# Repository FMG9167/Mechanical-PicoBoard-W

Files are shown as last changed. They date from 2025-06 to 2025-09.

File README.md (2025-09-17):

# Mechanical-PicoBoard-W
A wireless mechanical keyboard made using raspberry pi pico W.
This keyboard has a split spacebar, in which the middle button acts as a function key. The function keys are switched from numbers to QWERASDFZXCV and on the right side, OP[ acts as mouse buttons.




While I was making my Hackpad (Macropad), I saw people making keyboards and I realized that I actually didnt knew how a mechanical keyboard works. So what better way to learn than to make one yourself!

# CAD




# PCB



 


# Firmware

For the Firmware, I used KMK with CircuitPy.

# BOM

1x Raspberyy Pi Pico W   - 599 inr <br>
70x Switches             - 1225 inr <br>
1x Keycap Set            - 2199 inr <br>
5x Stabilizers           - 500 inr <br>
1x Battery Holder        - 59 inr <br>
100x 1N4148 Diodes       - 99 inr <br>
5x PCB                   - 4320 inr <br>
40x Female Berg Strip    - 8.5 inr <br>
40x Male Berg Strip      - 6 inr <br>
M3x16mm Screw            - 0 inr <br>
Case                     - printing legion <br>

### TOTAL 9015.5 INR = 102.67 USD

With shipping it is 109.9 usd

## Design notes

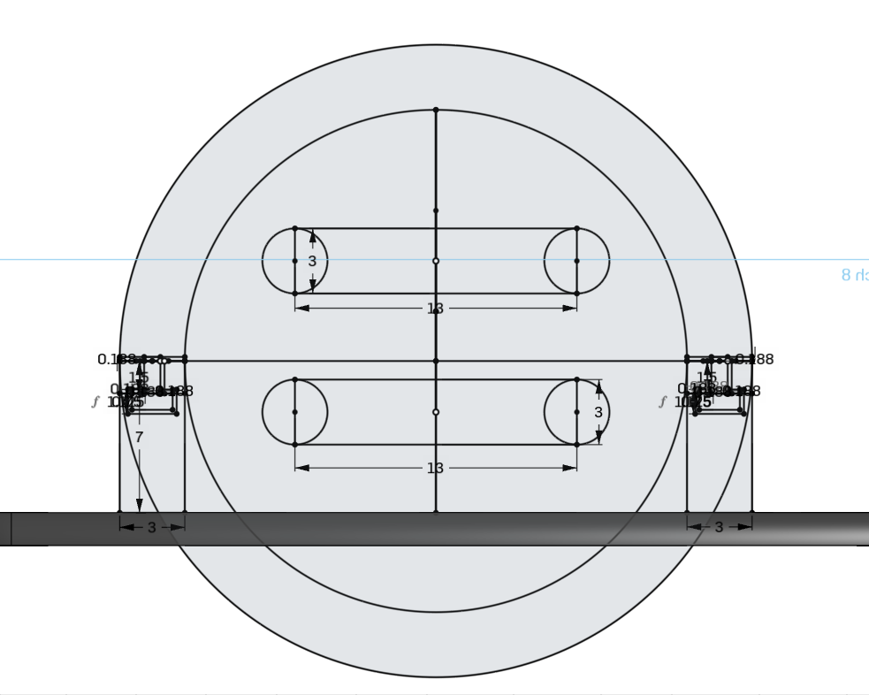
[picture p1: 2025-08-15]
images/Aug-15.png

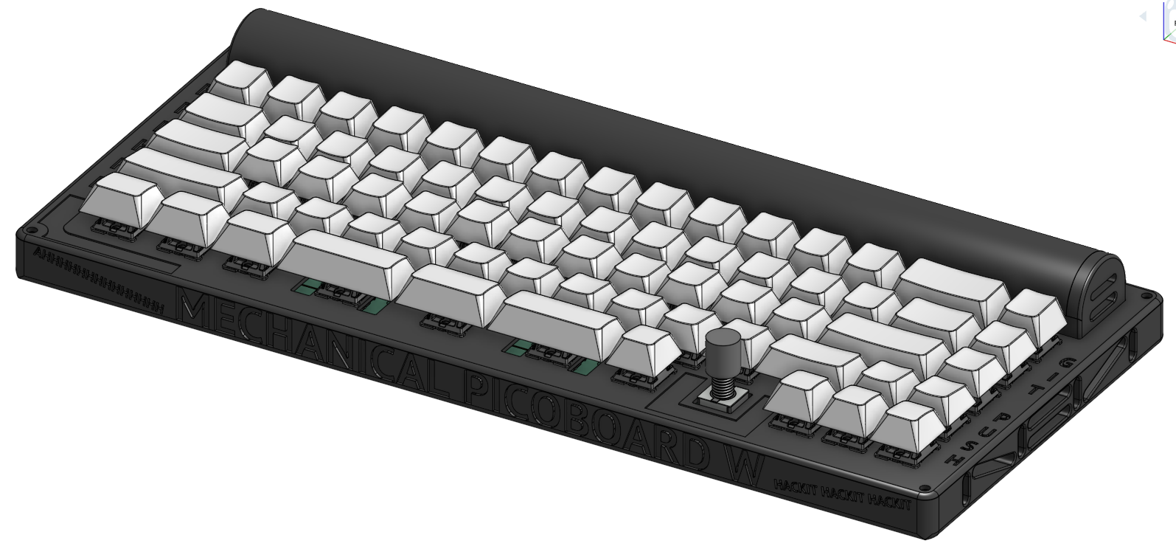
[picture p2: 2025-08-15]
images/Aug-15-4.png

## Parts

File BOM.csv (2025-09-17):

ITEM | UNIT COST | QUANTITY | TOTAL COST | REMARKS | SOURCE
Raspberry Pi Pico W | 599 | 1 | 599 | Other places it is out of stock | https://makerbazar.in/products/raspberry-pi-pico-development-boards?variant=47233117389040
Key Switches | 17.5 | 70 | 1225 | Comes in pack of 10 | https://stackskb.com/store/gateron-g-pro-3-0-yellow-ks-9-linear-switch-pack-of-10/
Key Caps | 2199 | 1 | 2199 |  | https://stackskb.com/store/sikakeyb-doubleshot-pbt-keycaps-two-tone-green-and-grey/
Stabilizers | 80 | 5 | 400 |  | https://stackskb.com/store/durock-white-plate-mount-stabilizers/?attribute_combination=2U
Battery Holder | 59 | 1 | 59 | out of stock literally everywhere | https://roboticsdna.in/product/18650-smd-smt-high-quality-single-battery-holder/
1N4148 Diodes | 0.99 | 100 | 99 | Comes in pack of 100 | https://makerbazar.in/products/dip-rectifier-diode-through-hole?variant=46889718120688
PCB | 864 | 5 | 4320 | Cheapest no customs option | https://robu.in/product/online-pcb-manufacturing-service/
Female berg strip | 0.2125 | 40 | 8.5 | Pack of 40 | https://robocraze.com/products/40x1-female-berg-strip?_pos=1&_sid=3452a2391&_ss=r
Male berg strip | 6.67 | 40 | 6 | Pack of 40 | https://makerbazar.in/products/berg-strip-40-pins
M3x16mm screws | 0 | 4 | 0 | Already have
Case | 0 | 0 | 0 | Printing Legion
 |  | INR | 9015.5
 |  | USD | 102.67 | Excluding shipping
I cant use Aliexpress as it end up costing more than current due to customs T-T
Maker Bazar shipping | 50
Robu shipping | 0
RoboticsDNA shipping | 85
Printing Legion | 500
StacksKB shipping | 100
 |  | INR | 9650.5
 |  | USD | 109.9 | Including taxes and shipping

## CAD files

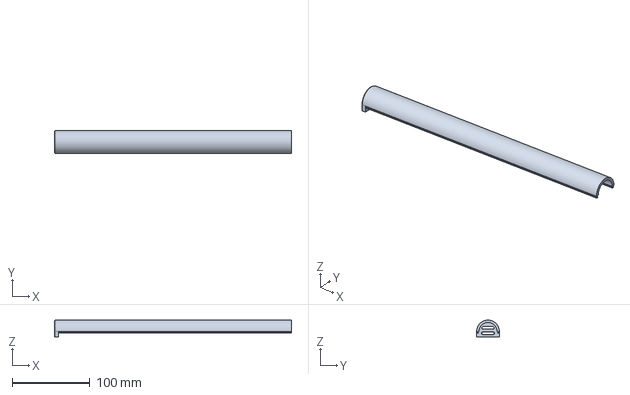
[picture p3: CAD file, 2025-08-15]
CAD/Cover.step
304.5 x 29.2 x 21.5 mm

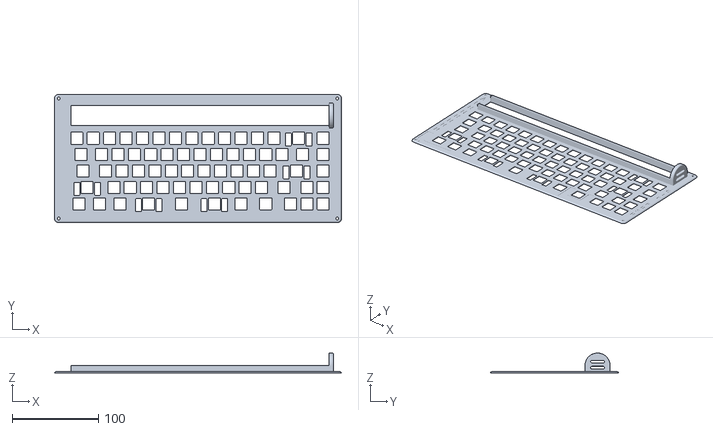
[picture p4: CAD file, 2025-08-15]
Production/Top.stl
332.9 x 148.9 x 23.1

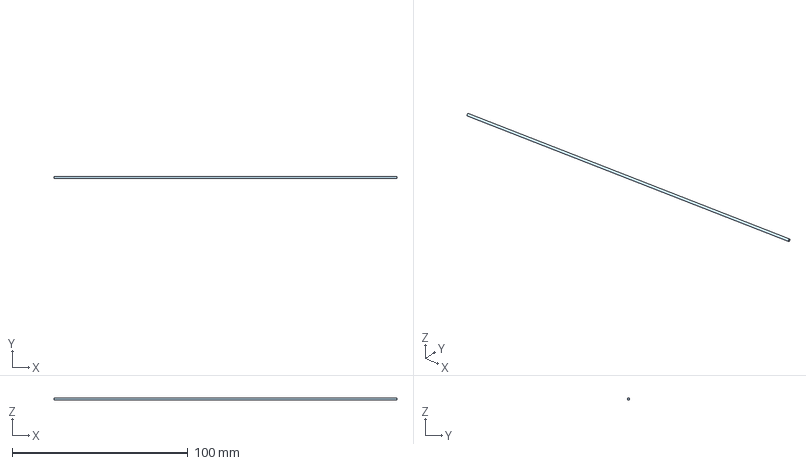
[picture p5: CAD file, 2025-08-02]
CAD/Rod.step
195.0 x 1.30 x 1.30 mm

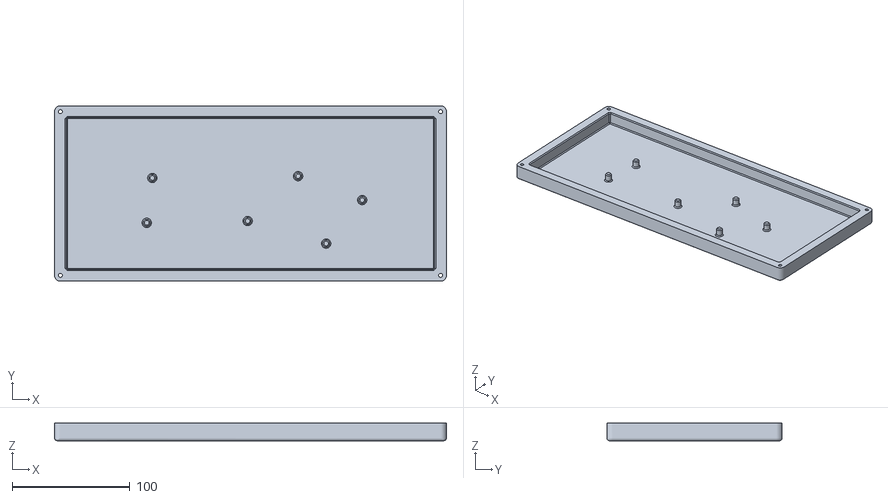
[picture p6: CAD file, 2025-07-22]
Production/Bottom.stl
333.0 x 149.0 x 15.0

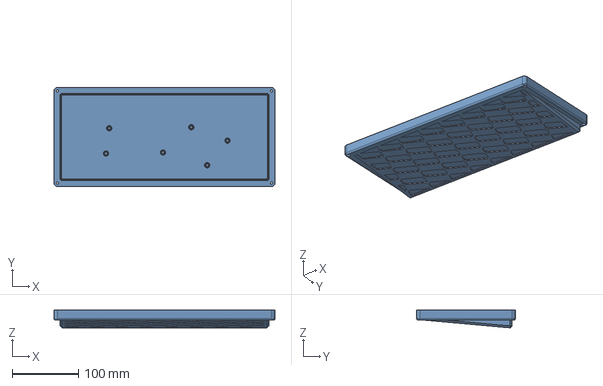
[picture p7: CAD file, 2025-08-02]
CAD/Bottom.step
333.0 x 149.0 x 26.7 mm

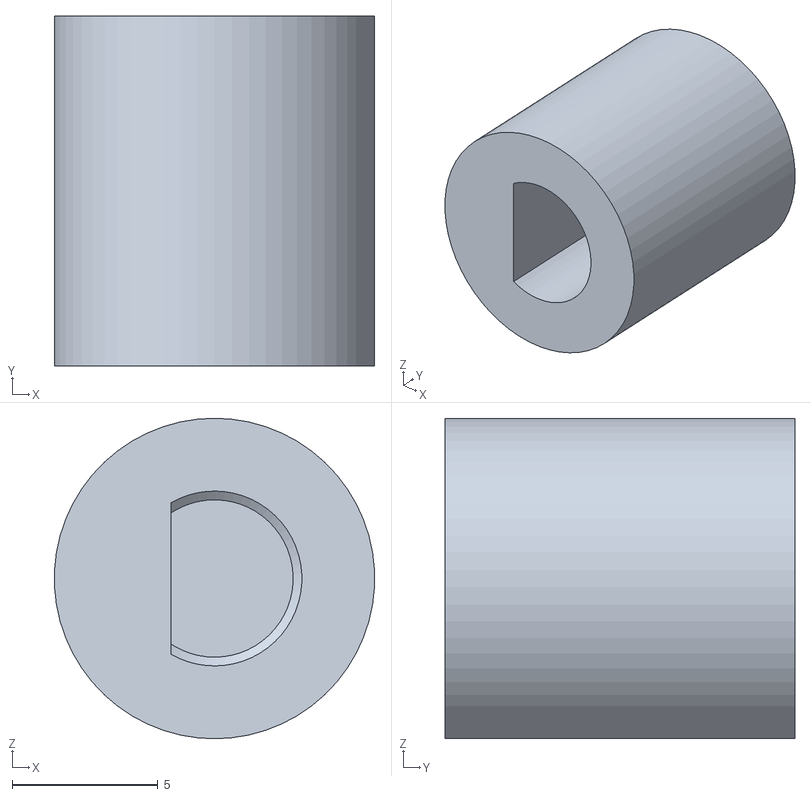
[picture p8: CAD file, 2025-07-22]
Production/Knob.stl
11.0 x 12.0 x 11.0

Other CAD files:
CAD/Top.step
Production/Cover.stl
CAD/Knob.step
CAD/Bottom.stl
CAD/Cover.stl
CAD/Rod.stl

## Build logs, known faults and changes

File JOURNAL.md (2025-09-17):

---
title: "Mechanical PicoBoard W"
author: "FMG"
description: "A wireless bluetooth keyboard made with raspberry pi pico w"
created_at: "2025-06-27"
---

## TOTAL TIME 46HRS

# June 28th: 

Today i started by making the basic schematic and researching on how the keyboard will actually work over bluetooth.

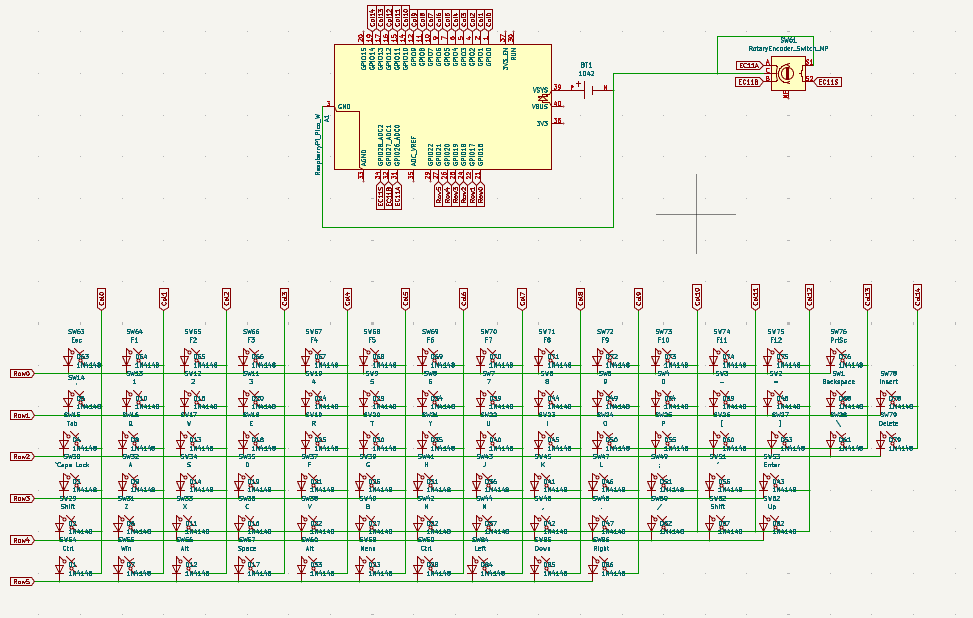
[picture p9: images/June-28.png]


My initial impression was that ill have to program pico via arduino ide for ble, but it turns out that kmk has support for ble.
Will probably save me a lot of trouble later on when making the firmware.

Also man did it take time to get all the keys in the schematic.

I will pretty sure change the matrix a lot while ill do the wiring in the pcb editor so i didnt think much about them right now.

**Time Spent: 5h**

# June 29th:

Today i started adding stuff on the pcb. I remembered that i can add the dxf of keyboard which helped a lot in placement of the keys, still it took a very long time (80 keys). Also i found an smd battery holder so im gonna be using that. Tomorrow ill probably work on the connections and if time remains, on the silkscreen art.

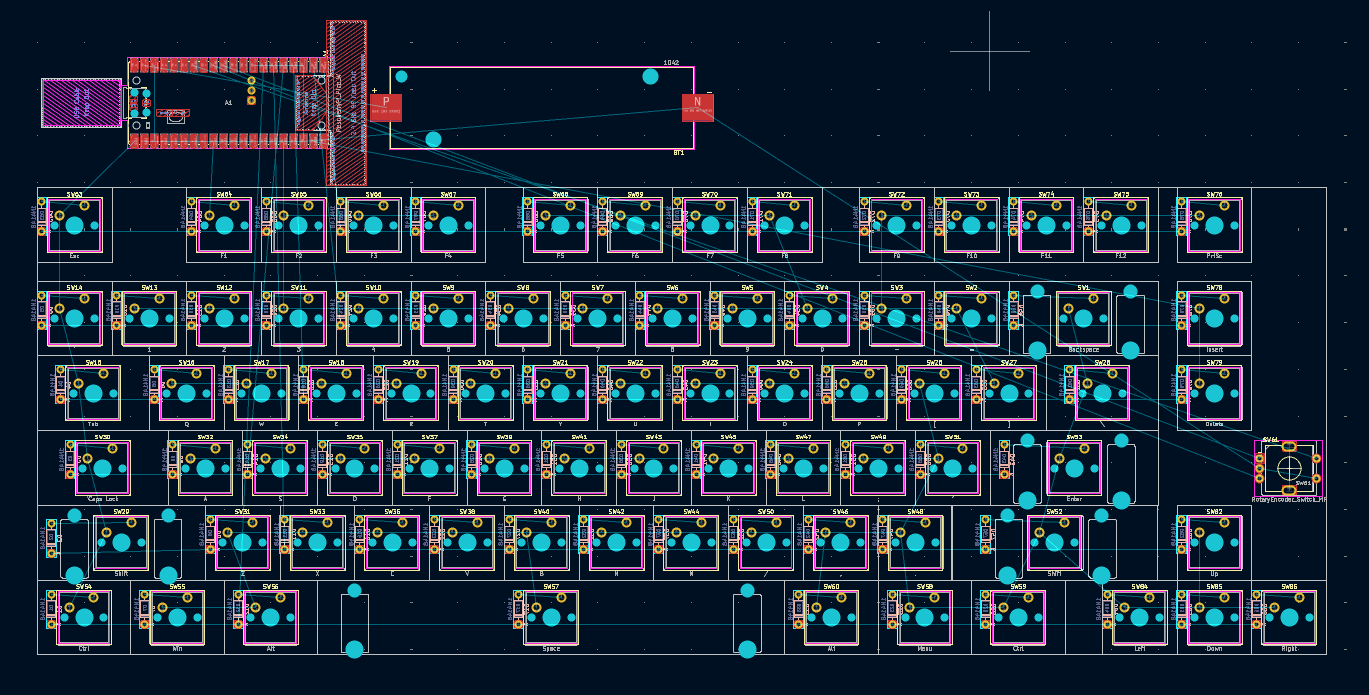
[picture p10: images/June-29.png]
unwired pcb


So many of the keys did not align with the dxf it was sooo painful having to fix most of the keys placement.

I also searched for some keycaps to use. Couldn't find anything cheap. Will either have them 3d printed or if i find some cheap enough keycaps ill use those.

**Time Spent: 4h**

# June 30th:

Today i wired all the diodes and switches. As i foreshadowed, i did change the schematic. But in the end i just gave up and created these long diagonal columns.

This time i actually used both the front and backside of the pcb, unlike in my macropad.

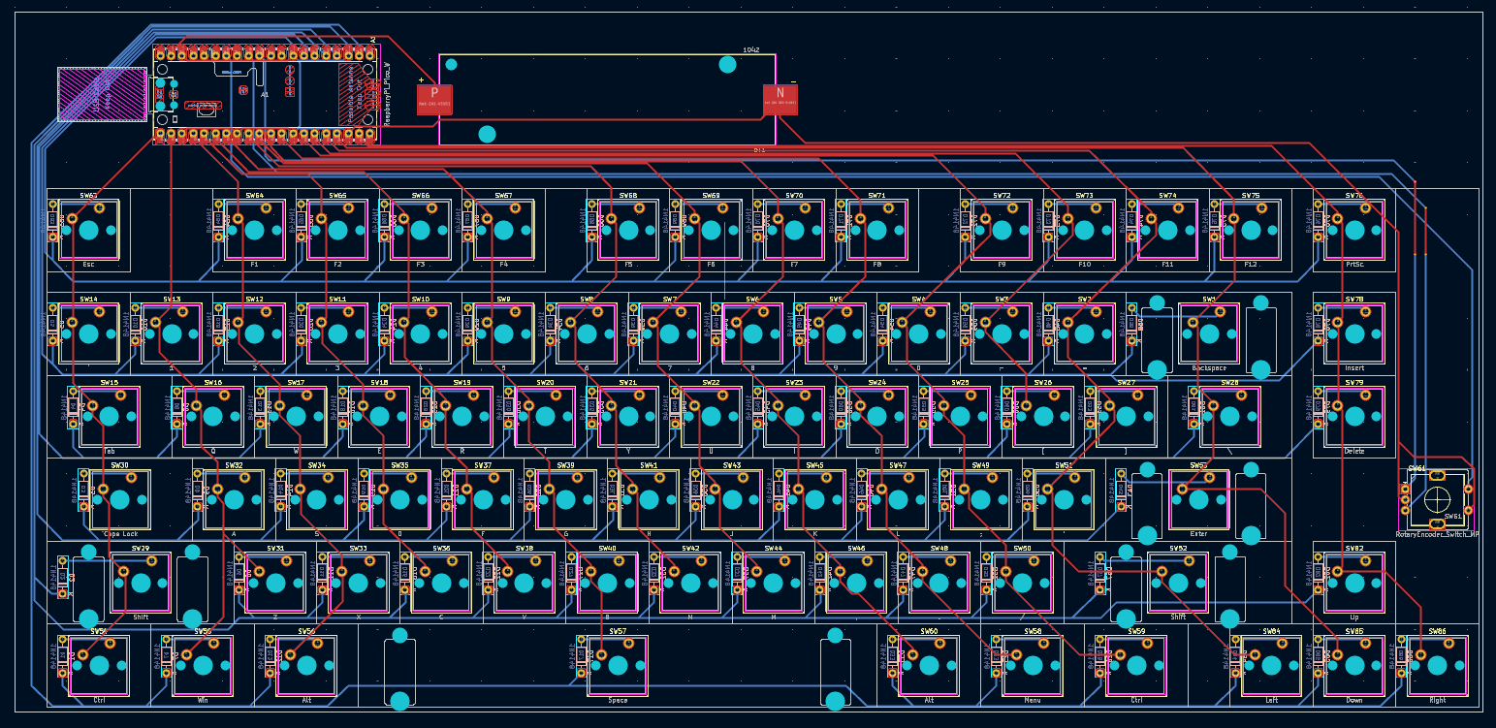
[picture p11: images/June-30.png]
wired pcb1


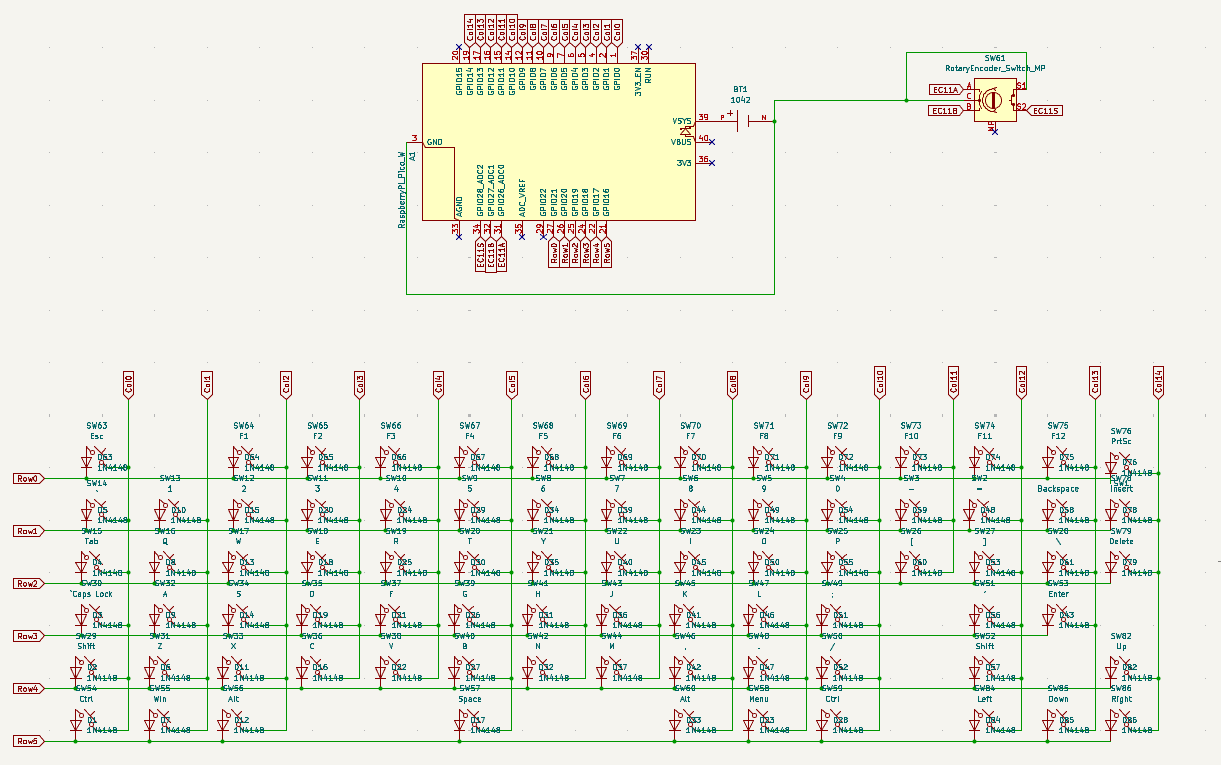
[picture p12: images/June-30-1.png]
updated schematic


Now that i look at it, i think the pico and battery would have been better off beside the arrow keys.

**Time Spent: 4h**

# July 5th:

I was pretty overwhelmed with studies for the past few days so couldnt do anything.
I did check out some other people's journals and realized that i am writing too less stuff, so ill try to add more stuff.

Today i am adding the models to my pcb footprints for an easier cad later on.

Found some good models on gradcad

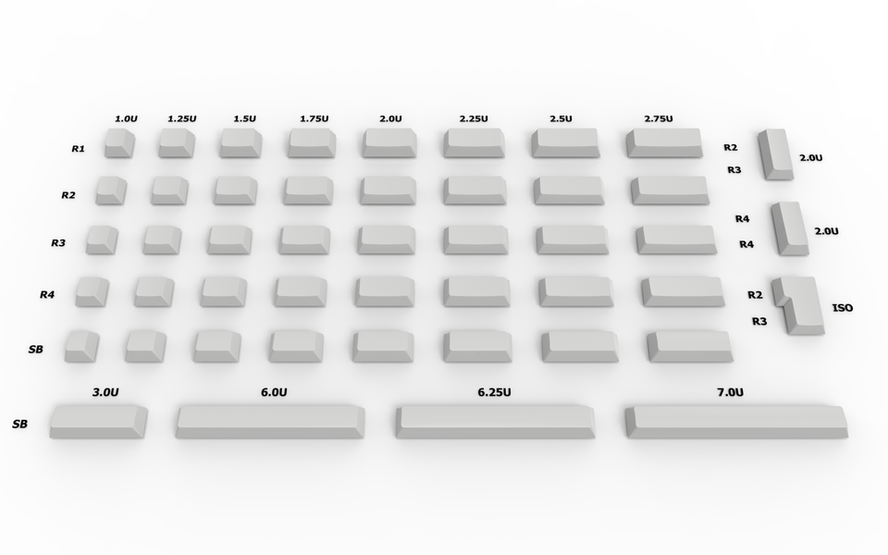
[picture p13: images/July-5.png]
Keycaps
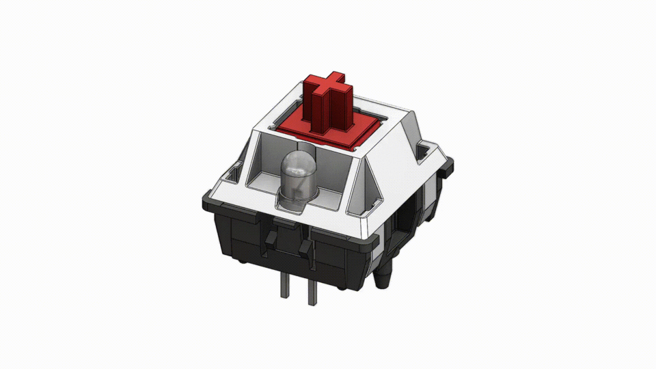
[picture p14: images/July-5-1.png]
Switches
 

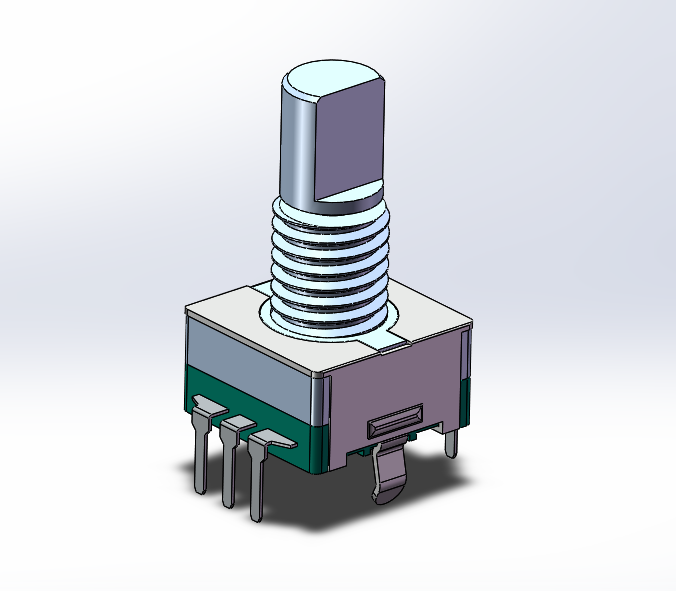
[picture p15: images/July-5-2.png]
rotary encoder
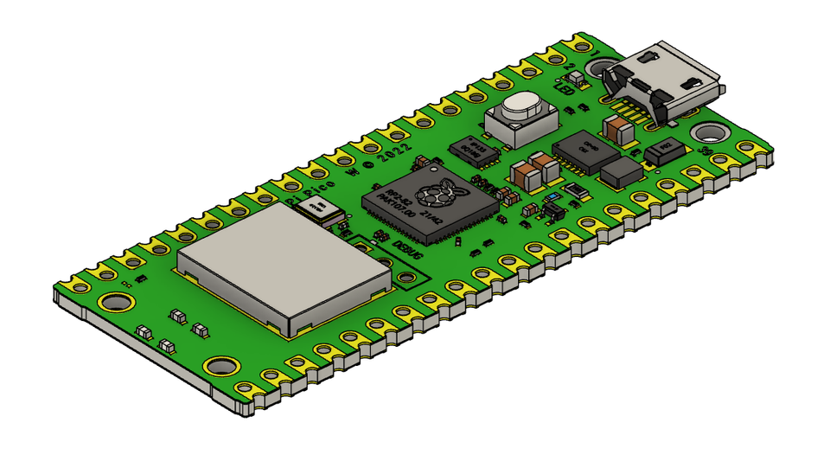
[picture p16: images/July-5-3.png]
pico w
 

I started first with the 1x1 keys as they were the maximum in number. Upon trying to save, it repeatedly gave me permission error, which i bypassed by saving them as new footprints.

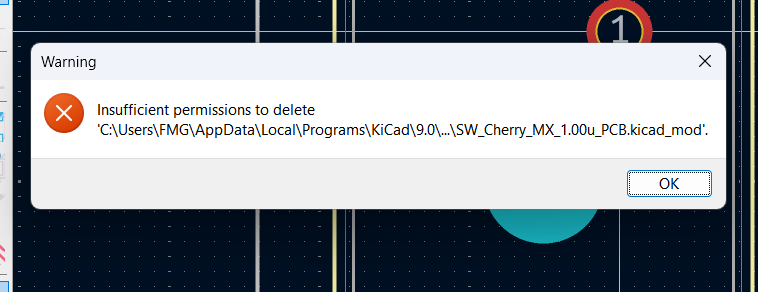
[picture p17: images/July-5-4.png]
error
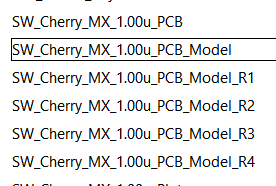
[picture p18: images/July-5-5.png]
bypass
 

The _Model only have the switch whereas _Model_Rx has keycaps corresponding to their row.

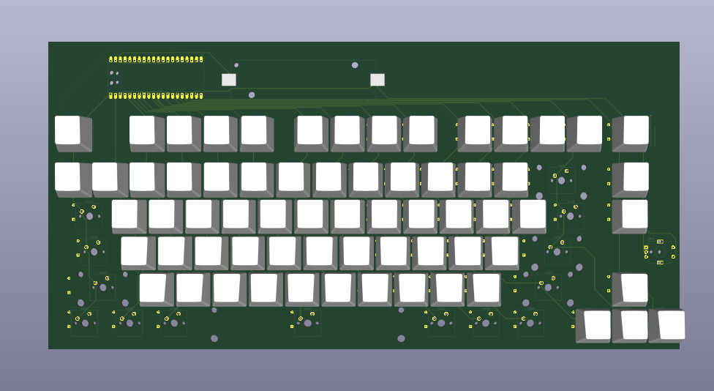
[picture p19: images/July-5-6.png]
Model with only u1


After this I took a short break, and then started with the rest of the keys

Since i cannot import stl, i first converted all the remaining keys to step, and then added them to their respective sizes and rows.

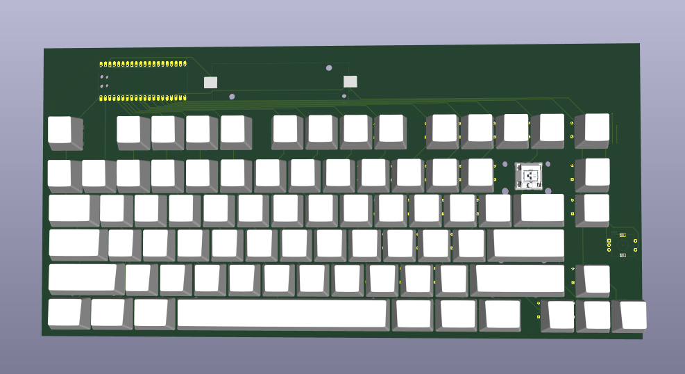
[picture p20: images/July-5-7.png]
All keys done*


I was pretty happy with the result and thought to myself that maybe i forgot to add the keycap for backspace and didnt think much about it.
Next I started the pico, encoder and battery holder models.

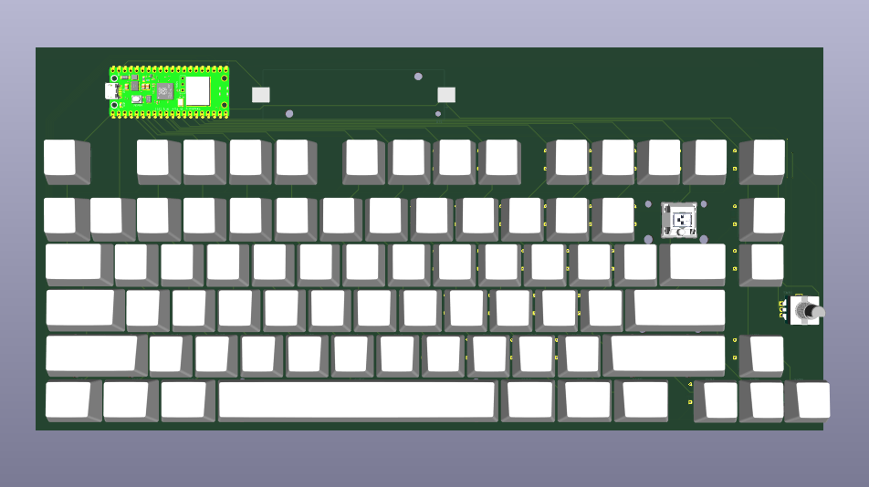
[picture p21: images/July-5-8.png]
Complete*


You might have noticed that the battery holder doesnt have its model and the backspace key its keycap.
I kept trying again and again trying to fix but they remained stubborn.

I then got frustrated and restarted KiCad, still the same.

Then i calmed myself down, switched to a different model for each of them. It updated. Then i switched back to their actual models AND IT FINALLY WORKED.

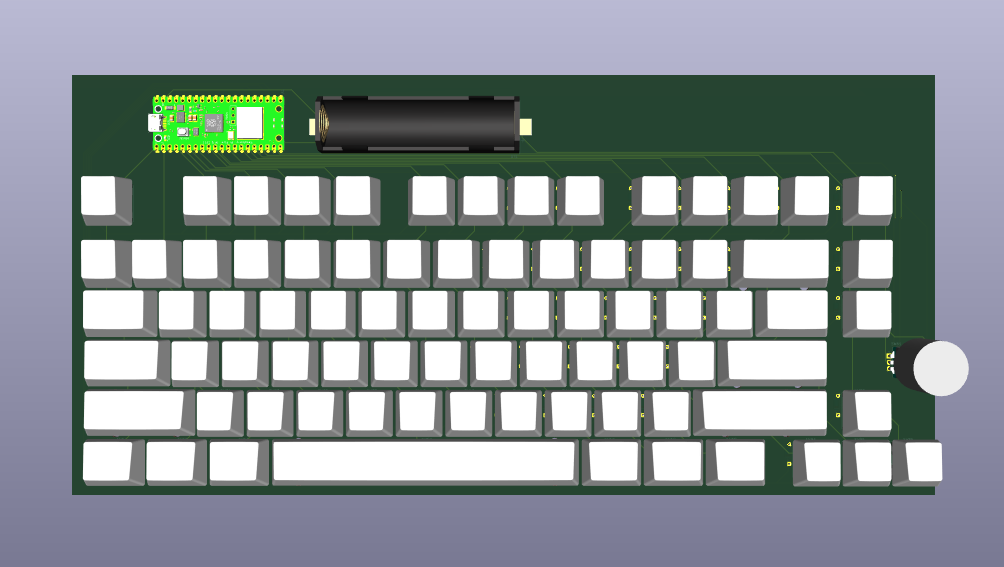
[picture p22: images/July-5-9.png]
Complete


[Ignore the knob i didnt know how tall to make it T-T]

**Time Spent: 6h**

# July 6th:

Starting the case today.

The basic outside is done, but the pcb does not look good in there

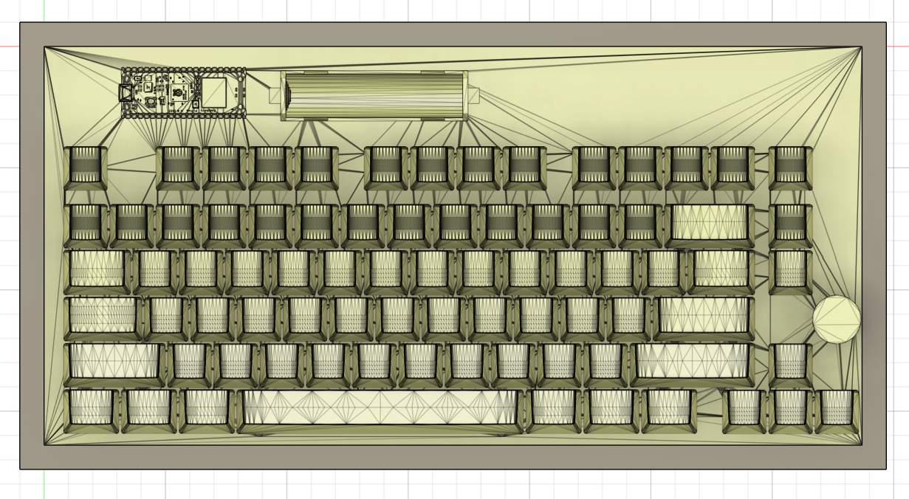
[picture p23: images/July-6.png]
CAD 1


aaaaaaand i scraped it cuz i couldnt get the dimensions correct. This time ill do the dimensions without already having the pcb imported as i cannot create rectangles off of the pcb's corners.

I finished the bottom case i think.

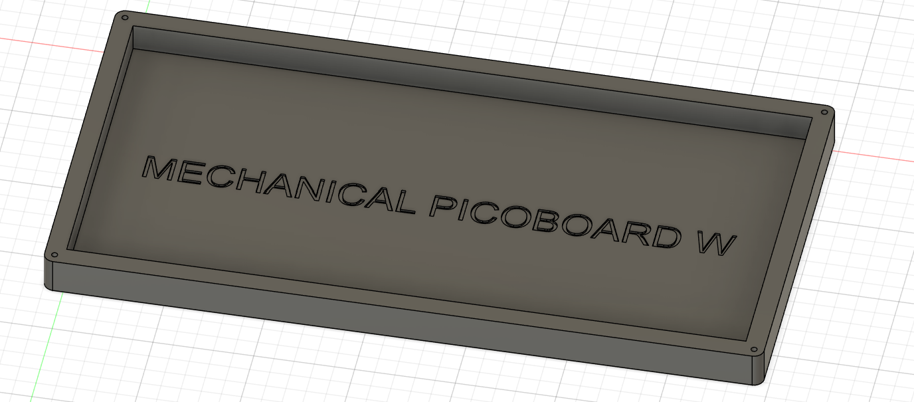
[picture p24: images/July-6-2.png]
Bottom


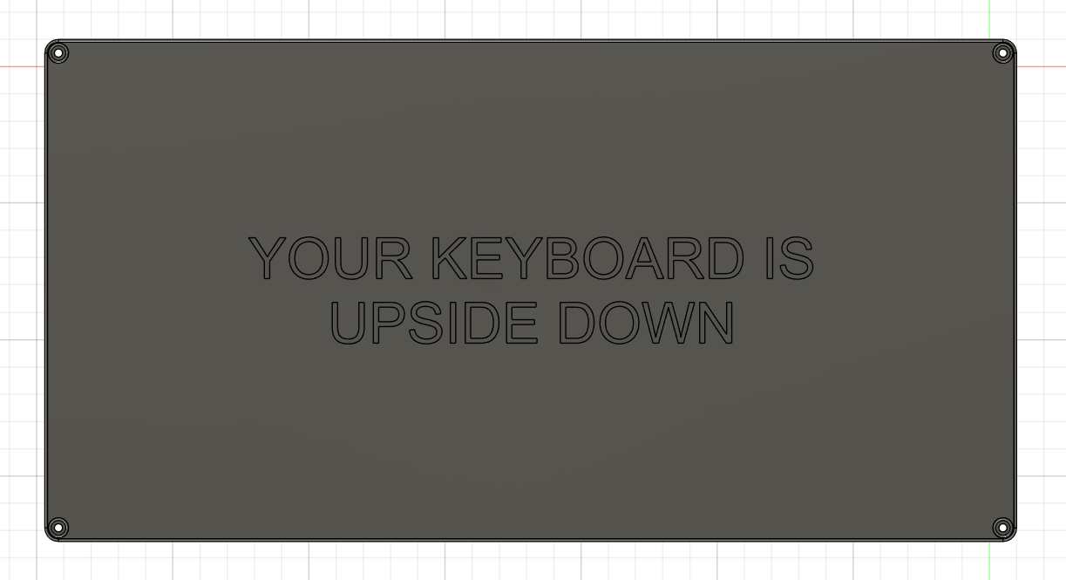
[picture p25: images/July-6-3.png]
Bottom's bottom


I will add a slot in the top cover through which ill change the battery. It will be covered with an acrylic sheet.

Also i found this new thingy which makes curved edges.
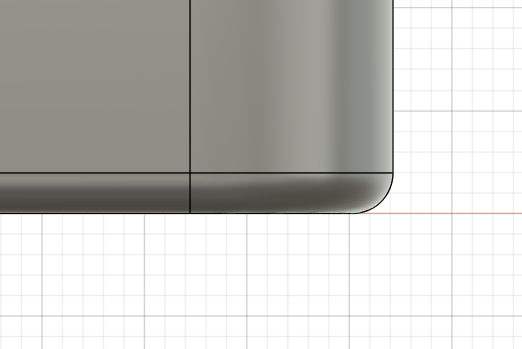
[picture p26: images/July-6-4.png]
Cool thing


I did that by going in the fillet option and setting corner type to "Setback"

Overall pretty happy with todays work

**Time spent: 5h**

# July 16th

It appears that my windows partition's mft got corrupted and i am unable to recover my data. So i will be restarting from scratch, and make sure to backup the kicad files as well.

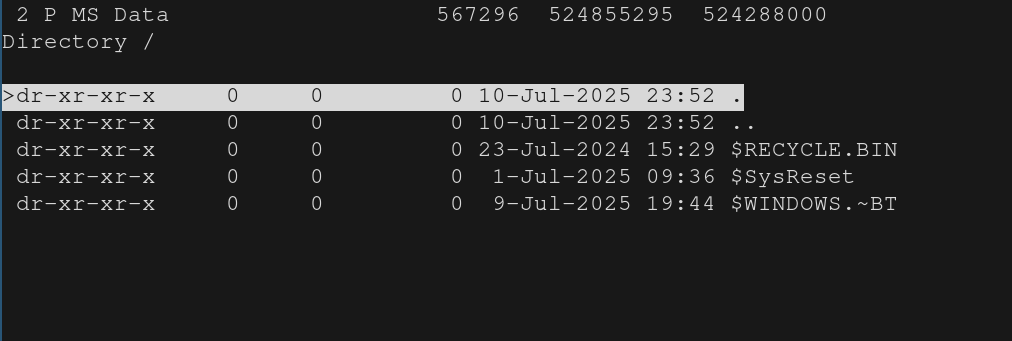
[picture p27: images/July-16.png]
Corrupted data


**Time spent: 0h**

# July 18th

Today, my plan is to redo the full pcb and probably finish the model for the case. My previous attempt taught me a lot so I think I can finish it today itself.

This time i decided to change the layout a bit as well. The function key will switch the keys with front legend to those keys, like function and w will be F2. On the right side are controls for mouse. I might change and add things to move the cursor as well.
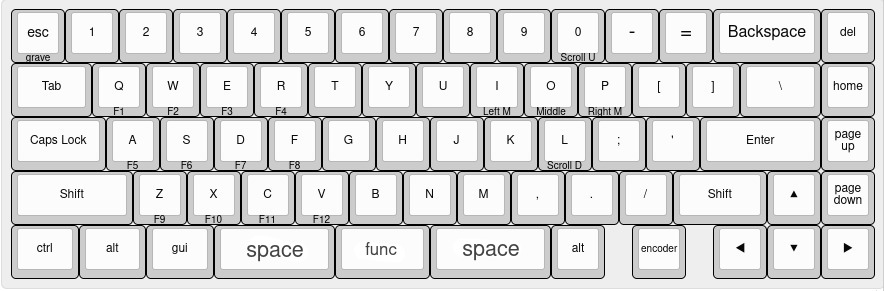
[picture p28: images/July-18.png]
Layout


Schematic is done. Forgot which library I used for the cell holder, but then realized that I had just used a battery symbol (checked previous entry).
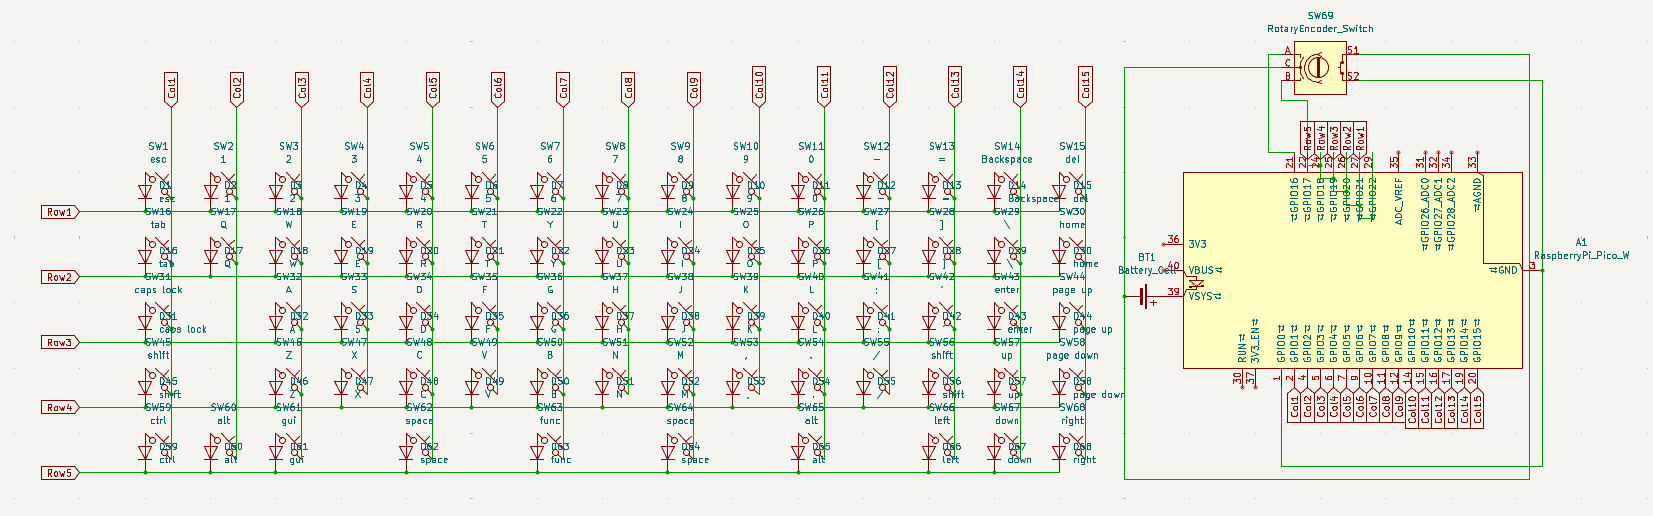
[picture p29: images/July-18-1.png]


Time to start making the PCB.

It was faster this time as I didnt think much about symmetry of diodes and just placed them. Routing was fun still.
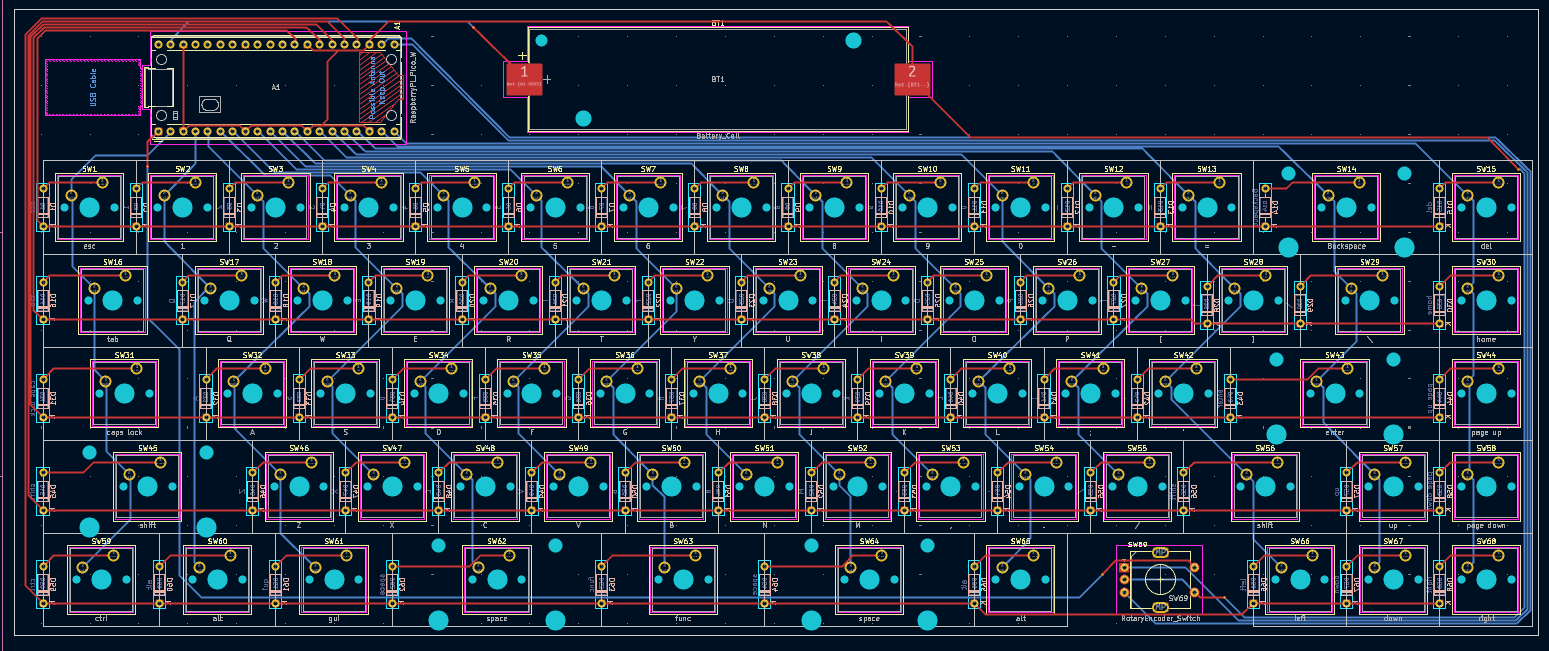
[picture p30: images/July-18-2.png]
PCB


Finished making the bottom of the case. Added a bit of incline as well for better hand positioning.
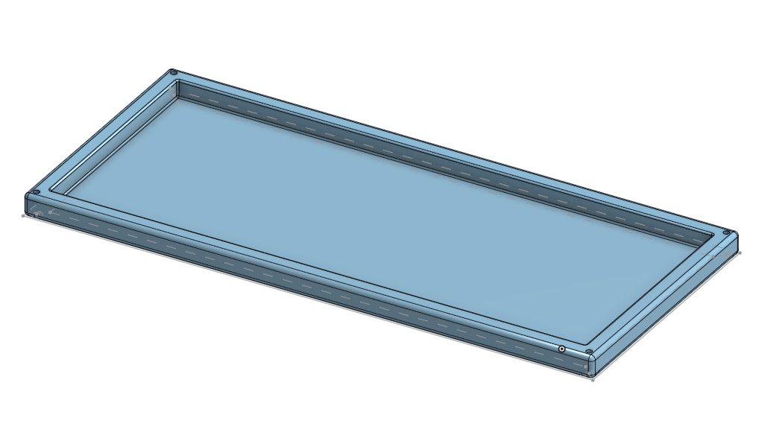
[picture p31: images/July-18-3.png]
Bottom Case


I am pretty frustrated by onshape cuz idk how to use it well so i am going to download fusion360 anyway I find. I downloaded VMWare and installed fusion360 there :).
Ok i spent a long time trying to make it work on vmware but it didnt so i am learning onshape only.

It took a long time but i finished the case. I couldnt add the keys cuz my pc couldnt handle 1170 parts T-T. I may add the keycaps tomorrow if I feel like it.
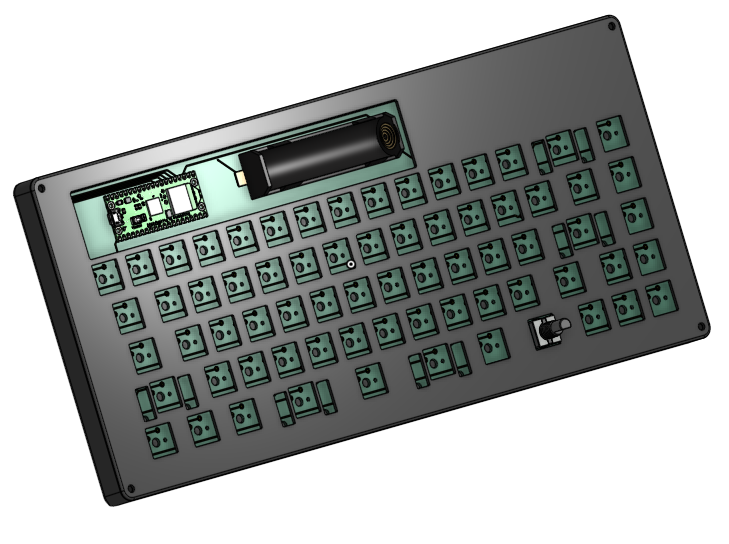
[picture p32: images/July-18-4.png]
Full Case


**Time spent: 10h**

# July 22nd
I couldn't do anything much on the previous days as I had back to back exams. Today I added all the keys and keycaps, and made a knob for the encoder

Adding the keys was simple, I just imported them into OnShape and then created 68 instances of it in the assembly.
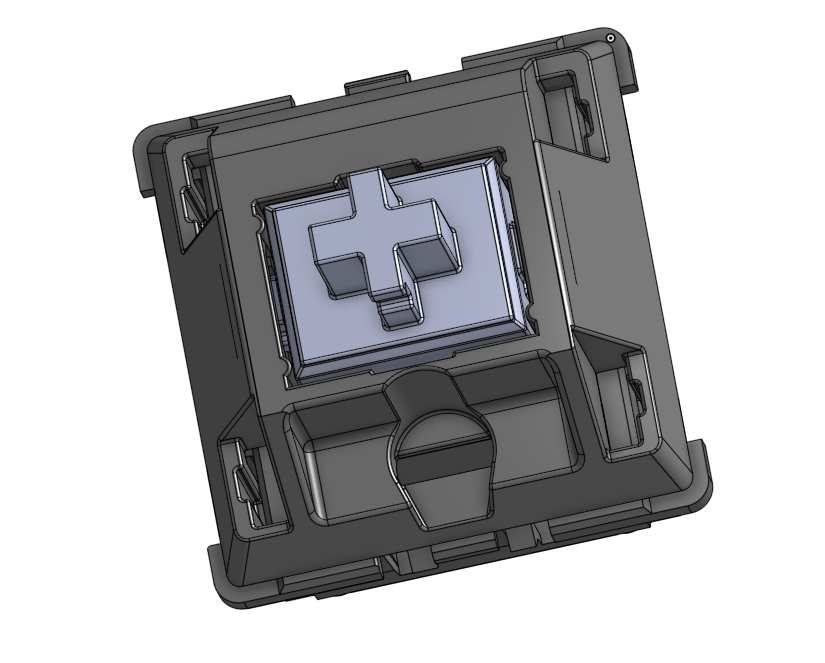
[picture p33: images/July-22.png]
Single Key

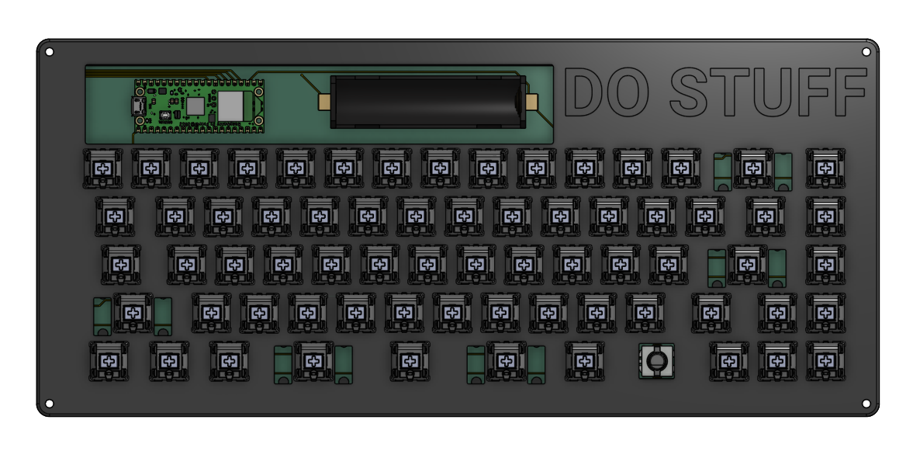
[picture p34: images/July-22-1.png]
All keys

I can feel the models taking toll on my browser.

Then i added the keycaps, and this took a long time. I had to create different assemblies for each type of keycap like R1 1u, R2 1u etc. It was a very tedious process, I know there is an easier way but I am not experienced with onshape enough for that (and am too lazy to google). When I was arranging the keycaps on top of the switches, I had to hide everything except the row I was working of because otherwise it would LAG LIKE HELL.
keycaps
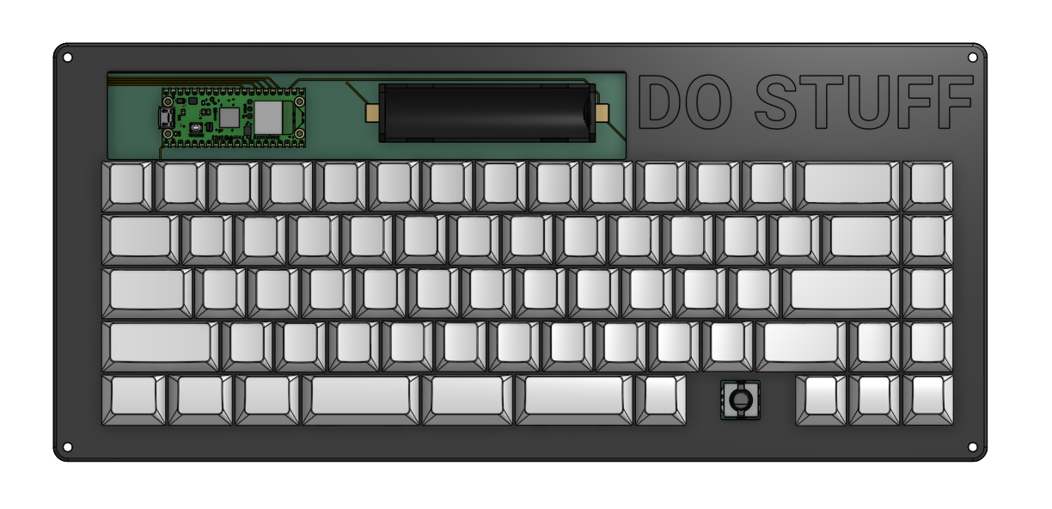
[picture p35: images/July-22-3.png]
Keycaps Arranged


Making the knob was pretty easy. I just subtracted the encoder's shaft from a cylinder.
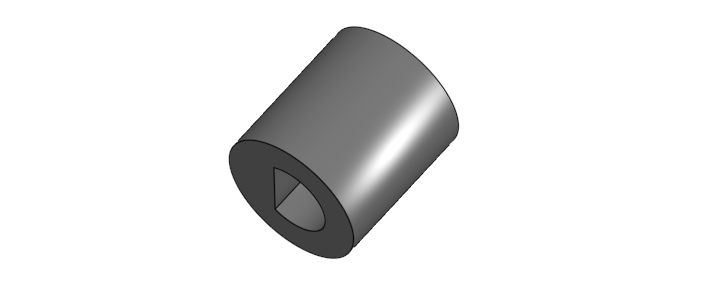
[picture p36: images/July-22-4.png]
Knob

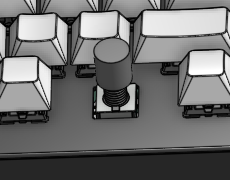
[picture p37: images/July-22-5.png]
Knob on Encoder


Also I added silkscreen art to my pcb :).
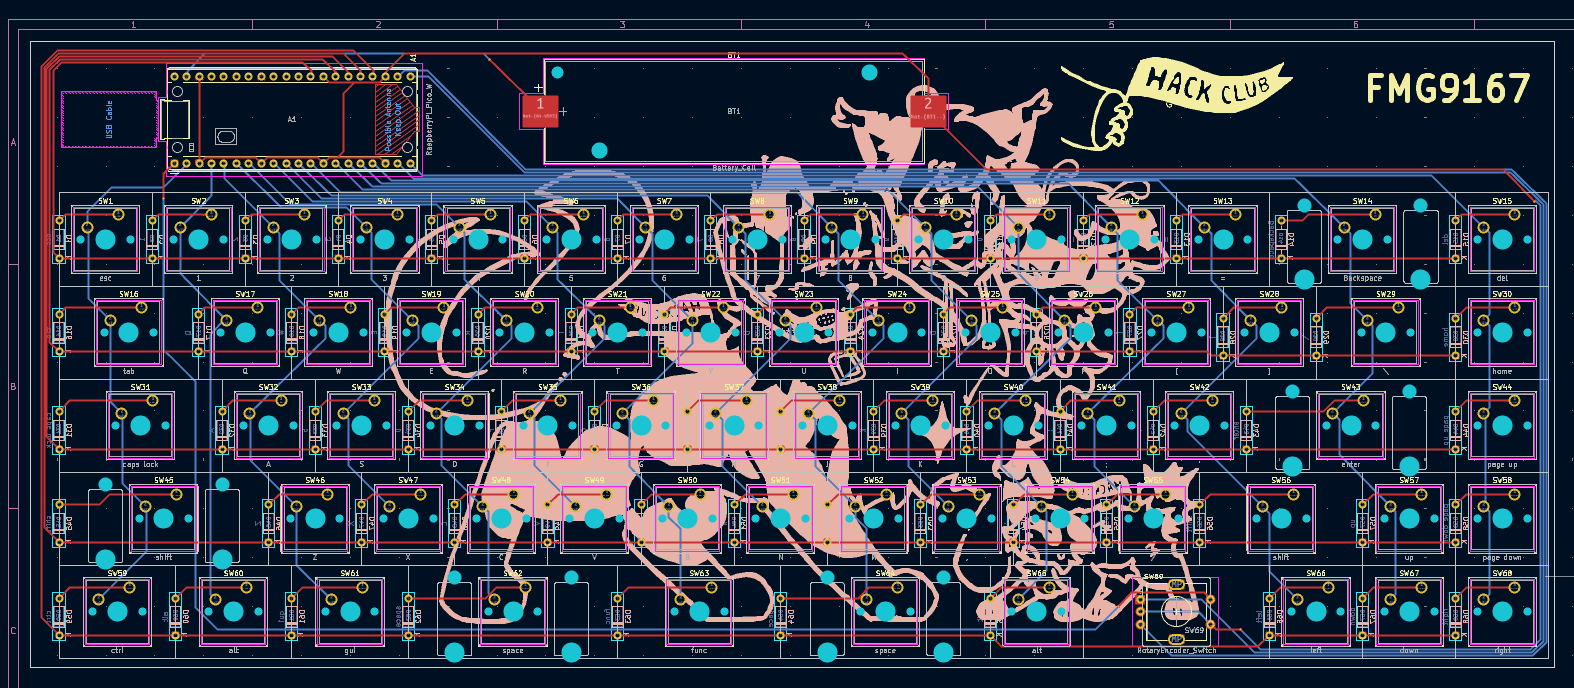
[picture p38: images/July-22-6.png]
Silkscreen art


When I thought that I could finally ship my project, I remembered that I have made absolutely no firmware whatsoever. So I guess ill do that now. Oh right BOM is also left.

Ok so I wrote the firmware while referencing to the documentation. I will adjust it later when I actually get the board.
Created the BOM.csv . I cant use AliExpress due to customs in India (They even blocked its domain).

**Time spent: 8h**

# August 2nd

Case was too simple so I made changes

 

**Time spent: 4h**

# August 15th

A lot of places I was getting stuff from ran out of them so i had to update the bom. I fixed the gerbers as well.
This happened in multiple sessions over 3 days so imma just write 2hrs.

**Time spent: 2h**

# August 17th

DID I SERIOUSLY FORGOT TO ORDER STABILIZERS AND REMEMBERED ABOUT THEM WHEN I RECEIVED MY ORDER????? that is so not good.

**Time spent: 0h**

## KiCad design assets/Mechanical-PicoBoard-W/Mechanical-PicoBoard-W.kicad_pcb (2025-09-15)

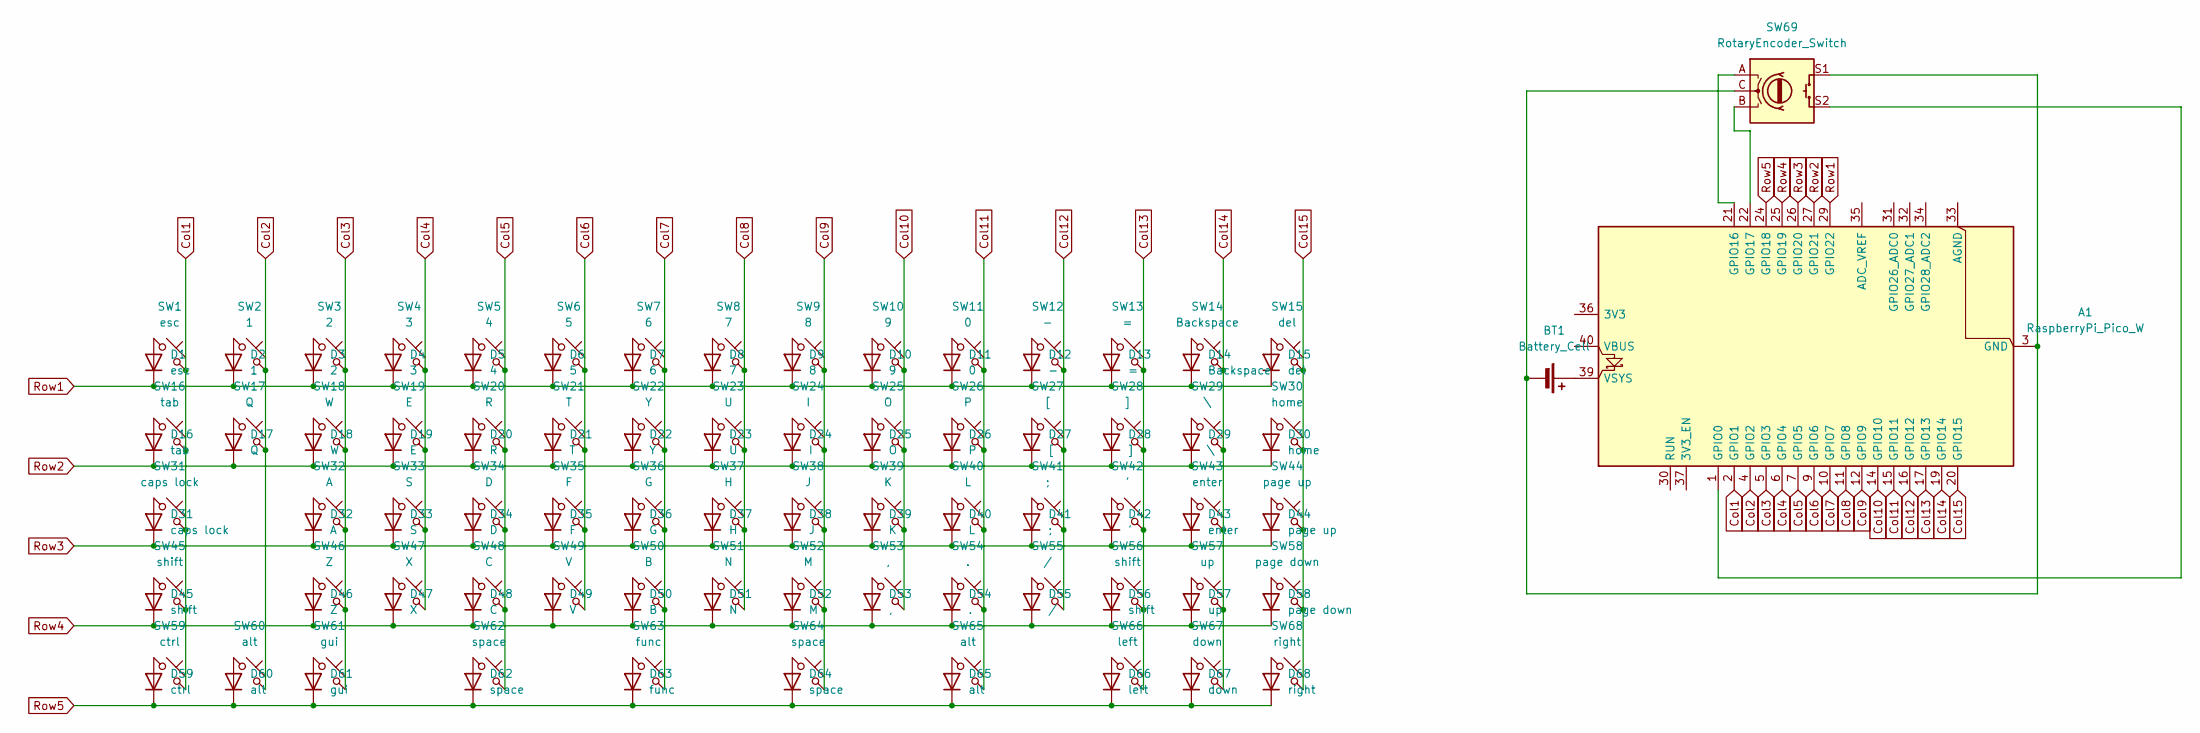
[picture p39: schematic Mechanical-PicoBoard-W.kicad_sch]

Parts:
A1: RaspberryPi_Pico_W; RaspberryPi_Pico_Common_THT_Model
BT1: Battery_Cell; BatteryHolder_Keystone_1042_1x18650
D1: esc; D_DO-35_SOD27_P7.62mm_Horizontal
D2: 1; D_DO-35_SOD27_P7.62mm_Horizontal
D3: 2; D_DO-35_SOD27_P7.62mm_Horizontal
D4: 3; D_DO-35_SOD27_P7.62mm_Horizontal
D5: 4; D_DO-35_SOD27_P7.62mm_Horizontal
D6: 5; D_DO-35_SOD27_P7.62mm_Horizontal
D7: 6; D_DO-35_SOD27_P7.62mm_Horizontal
D8: 7; D_DO-35_SOD27_P7.62mm_Horizontal
D9: 8; D_DO-35_SOD27_P7.62mm_Horizontal
D10: 9; D_DO-35_SOD27_P7.62mm_Horizontal
D11: 0; D_DO-35_SOD27_P7.62mm_Horizontal
D12: -; D_DO-35_SOD27_P7.62mm_Horizontal
D13: =; D_DO-35_SOD27_P7.62mm_Horizontal
D14: Backspace; D_DO-35_SOD27_P7.62mm_Horizontal
D15: del; D_DO-35_SOD27_P7.62mm_Horizontal
D16: tab; D_DO-35_SOD27_P7.62mm_Horizontal
D17: Q; D_DO-35_SOD27_P7.62mm_Horizontal
D18: W; D_DO-35_SOD27_P7.62mm_Horizontal
D19: E; D_DO-35_SOD27_P7.62mm_Horizontal
D20: R; D_DO-35_SOD27_P7.62mm_Horizontal
D21: T; D_DO-35_SOD27_P7.62mm_Horizontal
D22: Y; D_DO-35_SOD27_P7.62mm_Horizontal
D23: U; D_DO-35_SOD27_P7.62mm_Horizontal
D24: I; D_DO-35_SOD27_P7.62mm_Horizontal
D25: O; D_DO-35_SOD27_P7.62mm_Horizontal
D26: P; D_DO-35_SOD27_P7.62mm_Horizontal
D27: [; D_DO-35_SOD27_P7.62mm_Horizontal
D28: ]; D_DO-35_SOD27_P7.62mm_Horizontal
D29: \; D_DO-35_SOD27_P7.62mm_Horizontal
D30: home; D_DO-35_SOD27_P7.62mm_Horizontal
D31: caps lock; D_DO-35_SOD27_P7.62mm_Horizontal
D32: A; D_DO-35_SOD27_P7.62mm_Horizontal
D33: S; D_DO-35_SOD27_P7.62mm_Horizontal
D34: D; D_DO-35_SOD27_P7.62mm_Horizontal
D35: F; D_DO-35_SOD27_P7.62mm_Horizontal
D36: G; D_DO-35_SOD27_P7.62mm_Horizontal
D37: H; D_DO-35_SOD27_P7.62mm_Horizontal
D38: J; D_DO-35_SOD27_P7.62mm_Horizontal
D39: K; D_DO-35_SOD27_P7.62mm_Horizontal
D40: L; D_DO-35_SOD27_P7.62mm_Horizontal
D41: ;; D_DO-35_SOD27_P7.62mm_Horizontal
D42: '; D_DO-35_SOD27_P7.62mm_Horizontal
D43: enter; D_DO-35_SOD27_P7.62mm_Horizontal
D44: page up; D_DO-35_SOD27_P7.62mm_Horizontal
D45, D56: shift; D_DO-35_SOD27_P7.62mm_Horizontal
D46: Z; D_DO-35_SOD27_P7.62mm_Horizontal
D47: X; D_DO-35_SOD27_P7.62mm_Horizontal
D48: C; D_DO-35_SOD27_P7.62mm_Horizontal
D49: V; D_DO-35_SOD27_P7.62mm_Horizontal
D50: B; D_DO-35_SOD27_P7.62mm_Horizontal
D51: N; D_DO-35_SOD27_P7.62mm_Horizontal
D52: M; D_DO-35_SOD27_P7.62mm_Horizontal
D53: ,; D_DO-35_SOD27_P7.62mm_Horizontal
D54: .; D_DO-35_SOD27_P7.62mm_Horizontal
D55: /; D_DO-35_SOD27_P7.62mm_Horizontal
D57: up; D_DO-35_SOD27_P7.62mm_Horizontal
D58: page down; D_DO-35_SOD27_P7.62mm_Horizontal
D59: ctrl; D_DO-35_SOD27_P7.62mm_Horizontal
D60, D65: alt; D_DO-35_SOD27_P7.62mm_Horizontal
D61: gui; D_DO-35_SOD27_P7.62mm_Horizontal
D62, D64: space; D_DO-35_SOD27_P7.62mm_Horizontal
D63: func; D_DO-35_SOD27_P7.62mm_Horizontal
D66: left; D_DO-35_SOD27_P7.62mm_Horizontal
D67: down; D_DO-35_SOD27_P7.62mm_Horizontal
D68: right; D_DO-35_SOD27_P7.62mm_Horizontal
SW1: esc; SW_Cherry_MX_1.00u_PCB
SW2: 1; SW_Cherry_MX_1.00u_PCB
SW3: 2; SW_Cherry_MX_1.00u_PCB
SW4: 3; SW_Cherry_MX_1.00u_PCB
SW5: 4; SW_Cherry_MX_1.00u_PCB
SW6: 5; SW_Cherry_MX_1.00u_PCB
SW7: 6; SW_Cherry_MX_1.00u_PCB
SW8: 7; SW_Cherry_MX_1.00u_PCB
SW9: 8; SW_Cherry_MX_1.00u_PCB
SW10: 9; SW_Cherry_MX_1.00u_PCB
SW11: 0; SW_Cherry_MX_1.00u_PCB
SW12: -; SW_Cherry_MX_1.00u_PCB
SW13: =; SW_Cherry_MX_1.00u_PCB
SW14: Backspace; SW_Cherry_MX_2.00u_PCB
SW15: del; SW_Cherry_MX_1.00u_PCB
SW16: tab; SW_Cherry_MX_1.50u_PCB
SW17: Q; SW_Cherry_MX_1.00u_PCB
SW18: W; SW_Cherry_MX_1.00u_PCB
SW19: E; SW_Cherry_MX_1.00u_PCB
SW20: R; SW_Cherry_MX_1.00u_PCB
SW21: T; SW_Cherry_MX_1.00u_PCB
SW22: Y; SW_Cherry_MX_1.00u_PCB
SW23: U; SW_Cherry_MX_1.00u_PCB
SW24: I; SW_Cherry_MX_1.00u_PCB
SW25: O; SW_Cherry_MX_1.00u_PCB
SW26: P; SW_Cherry_MX_1.00u_PCB
SW27: [; SW_Cherry_MX_1.00u_PCB
SW28: ]; SW_Cherry_MX_1.00u_PCB
SW29: \; SW_Cherry_MX_1.50u_PCB
SW30: home; SW_Cherry_MX_1.00u_PCB
SW31: caps lock; SW_Cherry_MX_1.75u_PCB
SW32: A; SW_Cherry_MX_1.00u_PCB
SW33: S; SW_Cherry_MX_1.00u_PCB
SW34: D; SW_Cherry_MX_1.00u_PCB
SW35: F; SW_Cherry_MX_1.00u_PCB
SW36: G; SW_Cherry_MX_1.00u_PCB
SW37: H; SW_Cherry_MX_1.00u_PCB
SW38: J; SW_Cherry_MX_1.00u_PCB
SW39: K; SW_Cherry_MX_1.00u_PCB
SW40: L; SW_Cherry_MX_1.00u_PCB
SW41: ;; SW_Cherry_MX_1.00u_PCB
SW42: '; SW_Cherry_MX_1.00u_PCB
SW43: enter; SW_Cherry_MX_2.25u_PCB
SW44: page up; SW_Cherry_MX_1.00u_PCB
SW45: shift; SW_Cherry_MX_2.25u_PCB
SW46: Z; SW_Cherry_MX_1.00u_PCB
SW47: X; SW_Cherry_MX_1.00u_PCB
SW48: C; SW_Cherry_MX_1.00u_PCB
SW49: V; SW_Cherry_MX_1.00u_PCB
SW50: B; SW_Cherry_MX_1.00u_PCB
SW51: N; SW_Cherry_MX_1.00u_PCB
SW52: M; SW_Cherry_MX_1.00u_PCB
SW53: ,; SW_Cherry_MX_1.00u_PCB
SW54: .; SW_Cherry_MX_1.00u_PCB
SW55: /; SW_Cherry_MX_1.00u_PCB
SW56: shift; SW_Cherry_MX_1.75u_PCB
SW57: up; SW_Cherry_MX_1.00u_PCB
SW58: page down; SW_Cherry_MX_1.00u_PCB
SW59: ctrl; SW_Cherry_MX_1.25u_PCB
SW60: alt; SW_Cherry_MX_1.25u_PCB
SW61: gui; SW_Cherry_MX_1.25u_PCB
SW62, SW64: space; SW_Cherry_MX_2.25u_PCB
SW63: func; SW_Cherry_MX_1.75u_PCB
SW65: alt; SW_Cherry_MX_1.00u_PCB
SW66: left; SW_Cherry_MX_1.00u_PCB
SW67: down; SW_Cherry_MX_1.00u_PCB
SW68: right; SW_Cherry_MX_1.00u_PCB
SW69: RotaryEncoder_Switch; RotaryEncoder_Alps_EC11E-Switch_Vertical_H20mm_Model

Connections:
Col1: A1.2 (GPIO1), SW1.2, SW16.2, SW31.2, SW45.2, SW59.2
Col2: A1.4 (GPIO2), SW2.2, SW17.2, SW60.2
Col3: A1.5 (GPIO3), SW3.2, SW18.2, SW32.2, SW46.2, SW61.2
Col4: A1.6 (GPIO4), SW4.2, SW19.2, SW33.2, SW47.2
Col5: A1.7 (GPIO5), SW5.2, SW20.2, SW34.2, SW48.2, SW62.2
Col6: A1.9 (GPIO6), SW6.2, SW21.2, SW35.2, SW49.2
Col7: A1.10 (GPIO7), SW7.2, SW22.2, SW36.2, SW50.2, SW63.2
Col8: A1.11 (GPIO8), SW8.2, SW23.2, SW37.2, SW51.2
Col9: A1.12 (GPIO9), SW9.2, SW24.2, SW38.2, SW52.2, SW64.2
Col10: A1.14 (GPIO10), SW10.2, SW25.2, SW39.2, SW53.2
Col11: A1.15 (GPIO11), SW11.2, SW26.2, SW40.2, SW54.2, SW65.2
Col12: A1.16 (GPIO12), SW12.2, SW27.2, SW41.2, SW55.2
Col13: A1.17 (GPIO13), SW13.2, SW28.2, SW42.2, SW56.2, SW66.2
Col14: A1.19 (GPIO14), SW14.2, SW29.2, SW43.2, SW57.2, SW67.2
Col15: A1.20 (GPIO15), SW15.2, SW30.2, SW44.2, SW58.2, SW68.2
unnamed: A1.1 (GPIO0), SW69.S2
unnamed: A1.21 (GPIO16), SW69.A
unnamed: A1.22 (GPIO17), SW69.B
unnamed: A1.39 (VSYS), BT1.1 (+)
unnamed: A1.3 (GND), A1.8 (GND), A1.13 (GND), A1.18 (GND), A1.23 (GND), A1.28 (GND), A1.38 (GND), BT1.2 (-), SW69.C, SW69.S1
unnamed: D1.2 (A), SW1.1
unnamed: D2.2 (A), SW2.1
unnamed: D3.2 (A), SW3.1
unnamed: D4.2 (A), SW4.1
unnamed: D5.2 (A), SW5.1
unnamed: D6.2 (A), SW6.1
unnamed: D7.2 (A), SW7.1
unnamed: D8.2 (A), SW8.1
unnamed: D9.2 (A), SW9.1
unnamed: D10.2 (A), SW10.1
unnamed: D11.2 (A), SW11.1
unnamed: D12.2 (A), SW12.1
unnamed: D13.2 (A), SW13.1
unnamed: D14.2 (A), SW14.1
unnamed: D15.2 (A), SW15.1
unnamed: D16.2 (A), SW16.1
unnamed: D17.2 (A), SW17.1
unnamed: D18.2 (A), SW18.1
unnamed: D19.2 (A), SW19.1
unnamed: D20.2 (A), SW20.1
unnamed: D21.2 (A), SW21.1
unnamed: D22.2 (A), SW22.1
unnamed: D23.2 (A), SW23.1
unnamed: D24.2 (A), SW24.1
unnamed: D25.2 (A), SW25.1
unnamed: D26.2 (A), SW26.1
unnamed: D27.2 (A), SW27.1
unnamed: D28.2 (A), SW28.1
unnamed: D29.2 (A), SW29.1
unnamed: D30.2 (A), SW30.1
unnamed: D31.2 (A), SW31.1
unnamed: D32.2 (A), SW32.1
unnamed: D33.2 (A), SW33.1
unnamed: D34.2 (A), SW34.1
unnamed: D35.2 (A), SW35.1
unnamed: D36.2 (A), SW36.1
unnamed: D37.2 (A), SW37.1
unnamed: D38.2 (A), SW38.1
unnamed: D39.2 (A), SW39.1
unnamed: D40.2 (A), SW40.1
unnamed: D41.2 (A), SW41.1
unnamed: D42.2 (A), SW42.1
unnamed: D43.2 (A), SW43.1
unnamed: D44.2 (A), SW44.1
unnamed: D45.2 (A), SW45.1
unnamed: D46.2 (A), SW46.1
unnamed: D47.2 (A), SW47.1
unnamed: D48.2 (A), SW48.1
unnamed: D49.2 (A), SW49.1
unnamed: D50.2 (A), SW50.1
unnamed: D51.2 (A), SW51.1
unnamed: D52.2 (A), SW52.1
unnamed: D53.2 (A), SW53.1
unnamed: D54.2 (A), SW54.1
unnamed: D55.2 (A), SW55.1
unnamed: D56.2 (A), SW56.1
unnamed: D57.2 (A), SW57.1
unnamed: D58.2 (A), SW58.1
unnamed: D59.2 (A), SW59.1
unnamed: D60.2 (A), SW60.1
unnamed: D61.2 (A), SW61.1
unnamed: D62.2 (A), SW62.1
unnamed: D63.2 (A), SW63.1
unnamed: D64.2 (A), SW64.1
unnamed: D65.2 (A), SW65.1
unnamed: D66.2 (A), SW66.1
unnamed: D67.2 (A), SW67.1
unnamed: D68.2 (A), SW68.1
Row1: A1.29 (GPIO22), D1.1 (K), D2.1 (K), D3.1 (K), D4.1 (K), D5.1 (K), D6.1 (K), D7.1 (K), D8.1 (K), D9.1 (K), D10.1 (K), D11.1 (K), D12.1 (K), D13.1 (K), D14.1 (K), D15.1 (K)
Row2: A1.27 (GPIO21), D16.1 (K), D17.1 (K), D18.1 (K), D19.1 (K), D20.1 (K), D21.1 (K), D22.1 (K), D23.1 (K), D24.1 (K), D25.1 (K), D26.1 (K), D27.1 (K), D28.1 (K), D29.1 (K), D30.1 (K)
Row3: A1.26 (GPIO20), D31.1 (K), D32.1 (K), D33.1 (K), D34.1 (K), D35.1 (K), D36.1 (K), D37.1 (K), D38.1 (K), D39.1 (K), D40.1 (K), D41.1 (K), D42.1 (K), D43.1 (K), D44.1 (K)
Row4: A1.25 (GPIO19), D45.1 (K), D46.1 (K), D47.1 (K), D48.1 (K), D49.1 (K), D50.1 (K), D51.1 (K), D52.1 (K), D53.1 (K), D54.1 (K), D55.1 (K), D56.1 (K), D57.1 (K), D58.1 (K)
Row5: A1.24 (GPIO18), D59.1 (K), D60.1 (K), D61.1 (K), D62.1 (K), D63.1 (K), D64.1 (K), D65.1 (K), D66.1 (K), D67.1 (K), D68.1 (K)

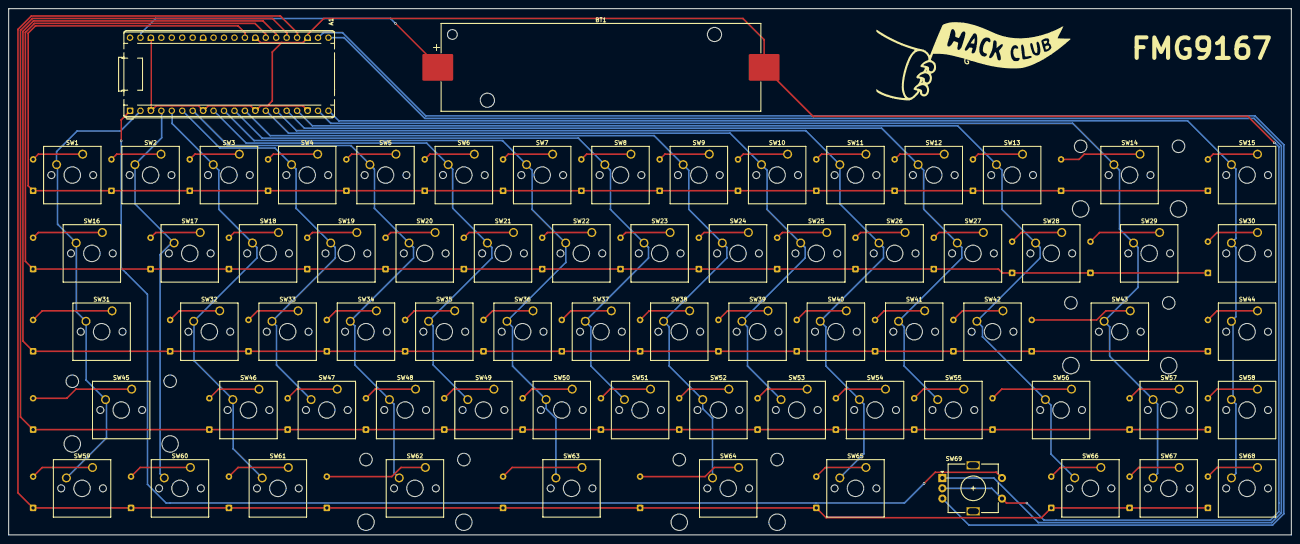
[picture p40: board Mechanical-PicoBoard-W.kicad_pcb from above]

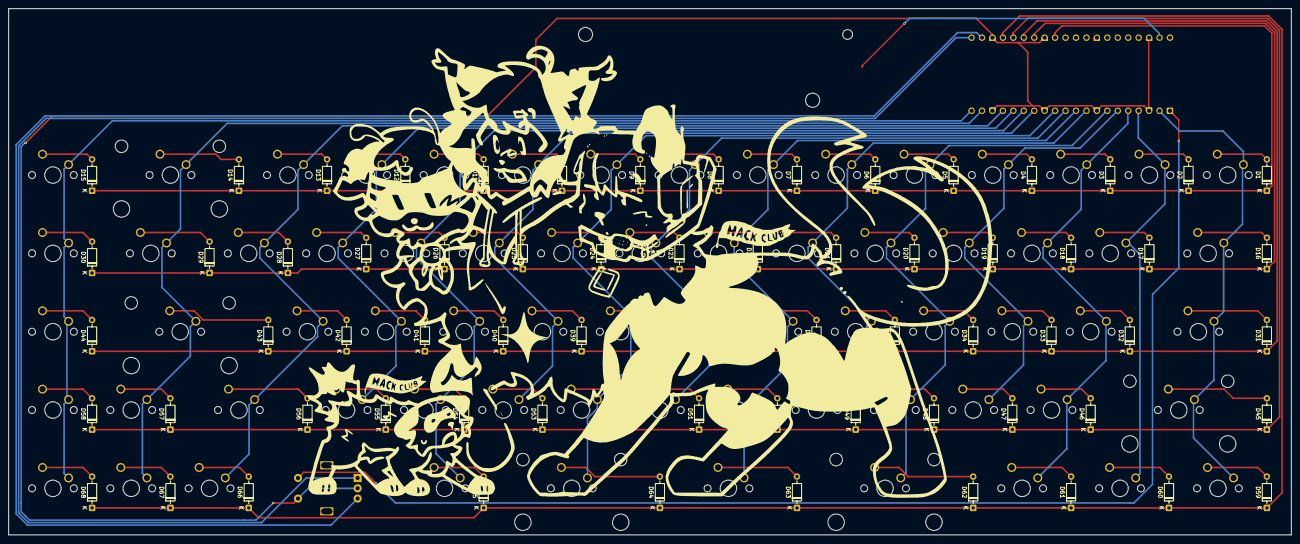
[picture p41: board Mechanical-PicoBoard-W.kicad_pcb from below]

Board: 2 copper layers, 312.0 x 128.0 mm, 139 parts (68 on the bottom side), 93 nets.

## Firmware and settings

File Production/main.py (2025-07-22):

import board

from kmk.kmk_keyboard import KMKKeyboard
from kmk.keys import KC
from kmk.scanners import DiodeOrientation
from kmk.modules.layers import Layers
from kmk.modules.encoder import EncoderHandler
from kmk.hid import HIDModes


keyboard = KMKKeyboard()

encoder_handler = EncoderHandler()

keyboard.modules = [layers, encoder_handler]

encoder_handler.pins = ((board.GP16, board.GP17, board.GP0,),)
encoder_handler.map = [
    [((KC.VOLD,KC.VOLU,KC.MUTE),)]
]

keyboard.col_pins = (board.GP1,board.GP2,board.GP3,board.GP4,board.GP5,board.GP6,board.GP7,board.GP8,board.GP9,board.GP10,board.GP11,board.GP12,board.GP13,board.GP14,board.GP15)
keyboard.row_pins = (board.GP22,board.GP21,board.GP20,board.GP19,board.GP18)
keyboard.diode_orientation = DiodeOrientation.COL2ROW

keyboard.keymap = [

    # BASE
    [ KC.ESC,    KC.N1,   KC.N2,   KC.N3,   KC.N4,    KC.N5, KC.N6,    KC.N7, KC.N8,    KC.N9,    KC.N0,    KC.MINUS, KC.EQUAL,  KC.BSPACE, KC.DEL,
      KC.TAB,    KC.Q,    KC.W,    KC.E,    KC.R,     KC.T,  KC.Y,     KC.U,  KC.I,     KC.O,     KC.P,     KC.LBRC,  KC.RBRC,   KC.BSLS,   KC.HOME,
      KC.LCAP,   KC.NO,   KC.A,    KC.S,    KC.D,     KC.F,  KC.G,     KC.H,  KC.J,     KC.K,     KC.L,     KC.SCLN,  KC.QUOT,   KC.ENT,    KC.PGUP,
      KC.LSHIFT, KC.NO,   KC.Z,    KC.X,    KC.C,     KC.V,  KC.B,     KC.N,  KC.M,     KC.COMMA, KC.DOT,   KC.SLSH,  KC.RSHIFT, KC.UP,     KC.PGDN,
      KC.LCTRL,  KC,LALT, KC.LGUI, KC.NO,   KC.SPACE, KC.NO, KC.MO(1), KC.NO, KC.SPACE, KC.NO,    KC.RALT,  KC.NO,    KC.LEFT,   KC.DOWN,   KC.RIGHT],

    # FUNCTION
    [ KC.ESC,    KC.N1,   KC.N2,   KC.N3,   KC.N4,    KC.N5, KC.N6,    KC.N7, KC.N8,    KC.N9,       KC.MW_UP,  KC.MINUS,  KC.EQUAL,  KC.BSPACE, KC.DEL,
      KC.TAB,    KC.F1,   KC.F2,   KC.F3,   KC.F4,    KC.T,  KC.Y,     KC.U,  KC.I,     KC.MB_LB,    KC.MB_MMB, KC.MB_RB,  KC.RBRC,   KC.BSLS,   KC.HOME,
      KC.LCAP,   KC.F5,   KC.F6,   KC.F7,   KC.F8,    KC.F,  KC.G,     KC.H,  KC.J,     KC.K,        KC.MW_DN,  KC.SCLN,   KC.QUOT,   KC.ENT,    KC.PGUP,
      KC.LSHIFT, KC.F9,   KC.F10,  KC.F11,  KC.F12,   KC.V,  KC.B,     KC.N,  KC.M,     KC.COMMA,    KC.DOT,    KC.SLSH,   KC.RSHIFT, KC.UP,     KC.PGDN,
      KC.LCTRL,  KC,LALT, KC.LGUI, KC.NO,   KC.SPACE, KC.NO, KC.TRNS,  KC.NO, KC.SPACE, KC.NO,       KC.RALT,   KC.NO,     KC.LEFT,   KC.DOWN,   KC.RIGHT]
]

if __name__ == '__main__':
    keyboard.go(hid_type=HIDModes.BLE, ble_name='PicoBoard')

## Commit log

2025-07-06 started cad
2025-07-16 the sad day
    [Mechanical-PicoBoard-W.kicad_pcb, Mechanical-PicoBoard-W.kicad_sch]
2025-07-19 recovery day
    [Mechanical-PicoBoard-W-B_Cu.gbl, Mechanical-PicoBoard-W-B_Mask.gbs, Mechanical-PicoBoard-W-B_Paste.gbp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]
2025-07-22 Arranged Folders
    [BOM.csv, Bottom.stl, Knob.stl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]
2025-07-22 Forgot about this
    [Mechanical-PicoBoard-W-B_Cu.gbl, Mechanical-PicoBoard-W-B_Mask.gbs, Mechanical-PicoBoard-W-B_Paste.gbp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]
2025-07-23 Added step cad files
    [Bottom.step, Knob.step, Top.step]
2025-07-24 Added incline
    [Bottom.step, Bottom.stl]
2025-07-24 added case to bom
    [BOM.csv]
2025-07-24 added a leftover comma
    [BOM.csv]
2025-07-29 Added screws to bom
    [BOM.csv]
2025-08-02 made the case not so simple
    [Bottom.step, Bottom.stl, Cover.step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]
2025-08-15 Added update to the case
    [Cover.step, Cover.stl, Top.step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]
2025-09-15 updated pricing and fixed gerbers
    [BOM.csv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]
2025-09-17 i forgot about stabilizers :(
    [BOM.csv]
